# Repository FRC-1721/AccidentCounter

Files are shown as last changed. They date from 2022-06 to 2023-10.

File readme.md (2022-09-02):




Watch the [Youtube Video here.](https://www.youtube.com/watch?v=R463rN57n-0)

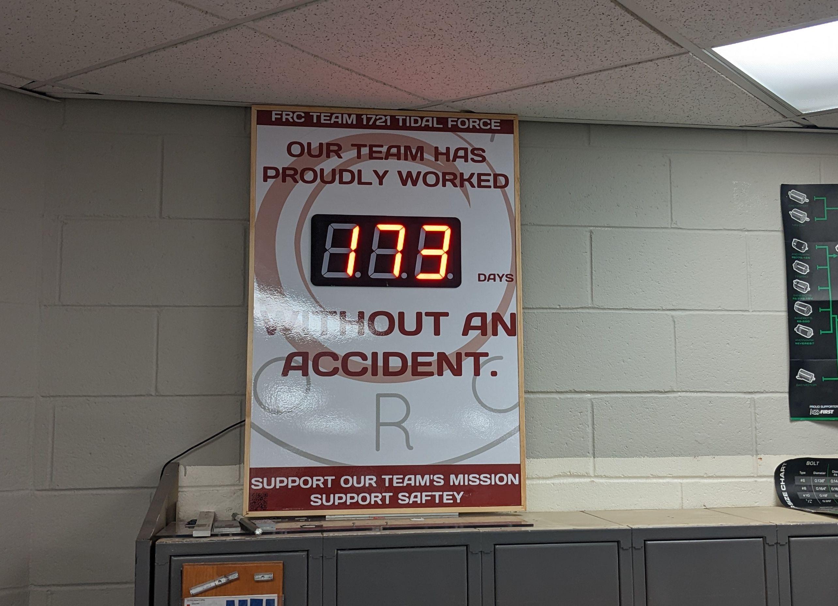
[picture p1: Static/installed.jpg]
The sign installed in the build space


# Welcome!

This repo contains all the firmware and hardware for Tidal Force's "Days
Worked Without Incident" counter.

If you're looking for the latest docs/builds, see our [Releases Page](https://github.com/FRC-1721/AccidentCounter/releases).

# Getting Started

First, clone this repo (and optionally checkout a branch)

```shell
git clone https://github.com/FRC-1721/AccidentCounter.git
cd AccidentCounter
git checkout new_board
```

# Init Submodules

Some libraries and resources are included as submodules, run the following
command to initialize them before opening the main sch

(If you get a missing library error, make sure to do this)

```shell
git submodule update --init --recursive
```

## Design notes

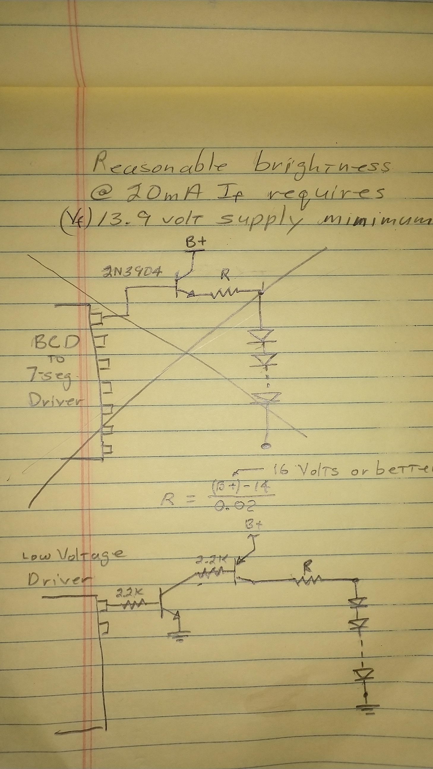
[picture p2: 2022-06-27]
CAD/schematic_with_circuit.jpeg

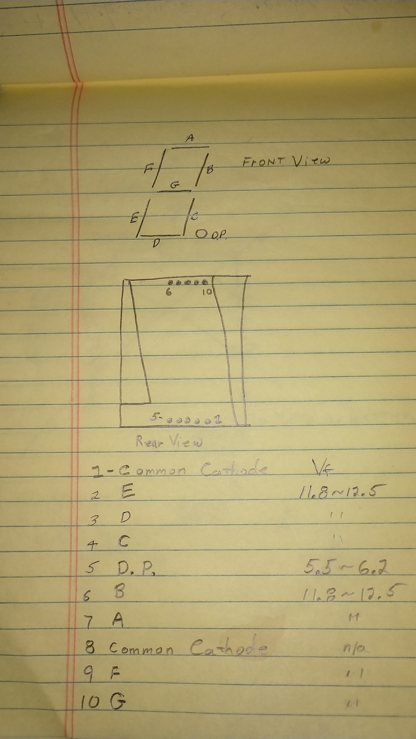
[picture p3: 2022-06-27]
CAD/schematic.png

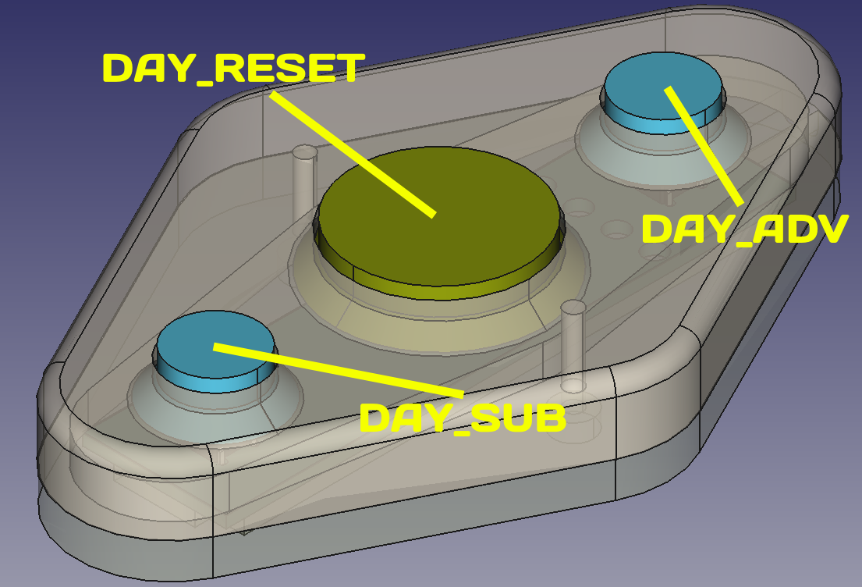
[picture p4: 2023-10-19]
Graphics/ExternalButton.png

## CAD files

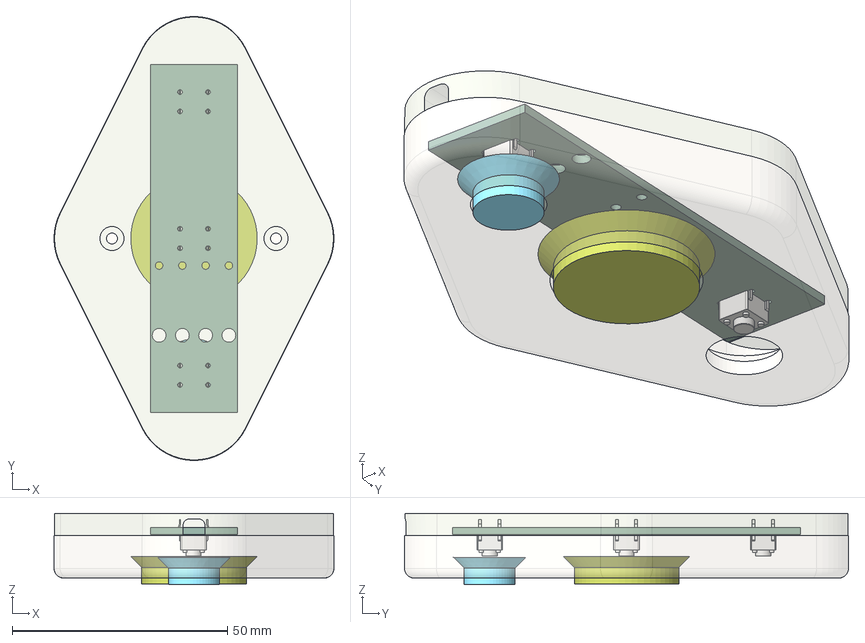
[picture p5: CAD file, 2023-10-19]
CAD/ExternalButton.FCStd
65.0 x 103.1 x 16.5 mm
Top
Small Button
Big Button
Bottom
_autosave-Controller PCB

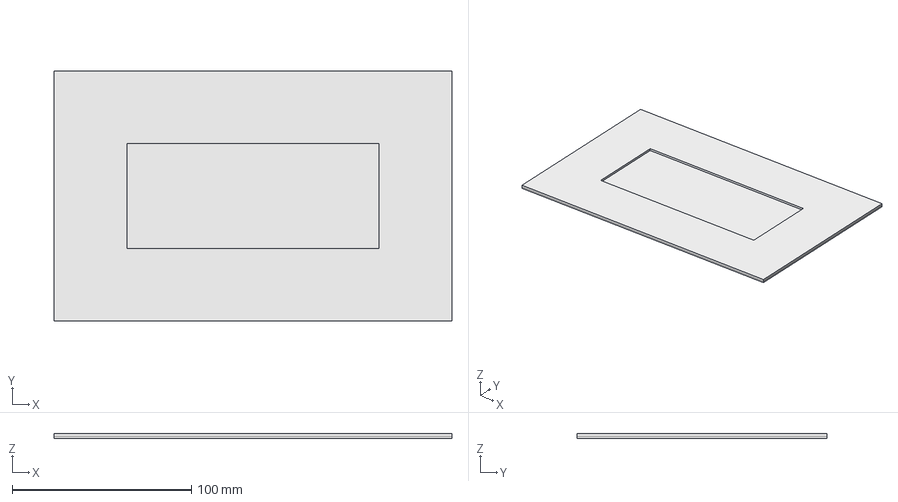
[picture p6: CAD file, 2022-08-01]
Hardware/Segment_Display_Board/Stencils and Templates/SolderMaskStencil.FCStd
222.2 x 139.7 x 2.60 mm

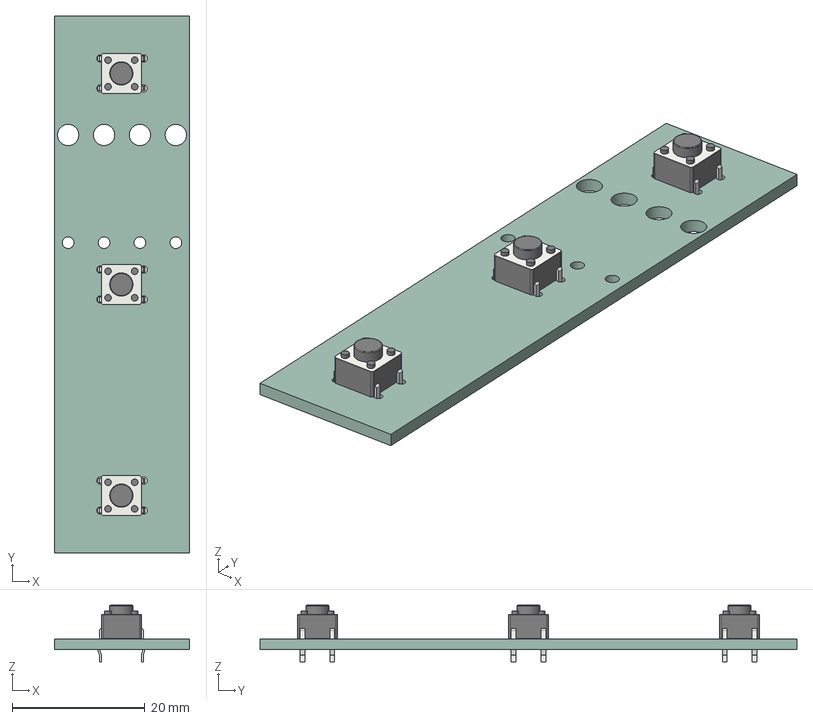
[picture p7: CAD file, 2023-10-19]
CAD/Controller.step
20.3 x 80.8 x 8.50 mm
_autosave-Controller PCB

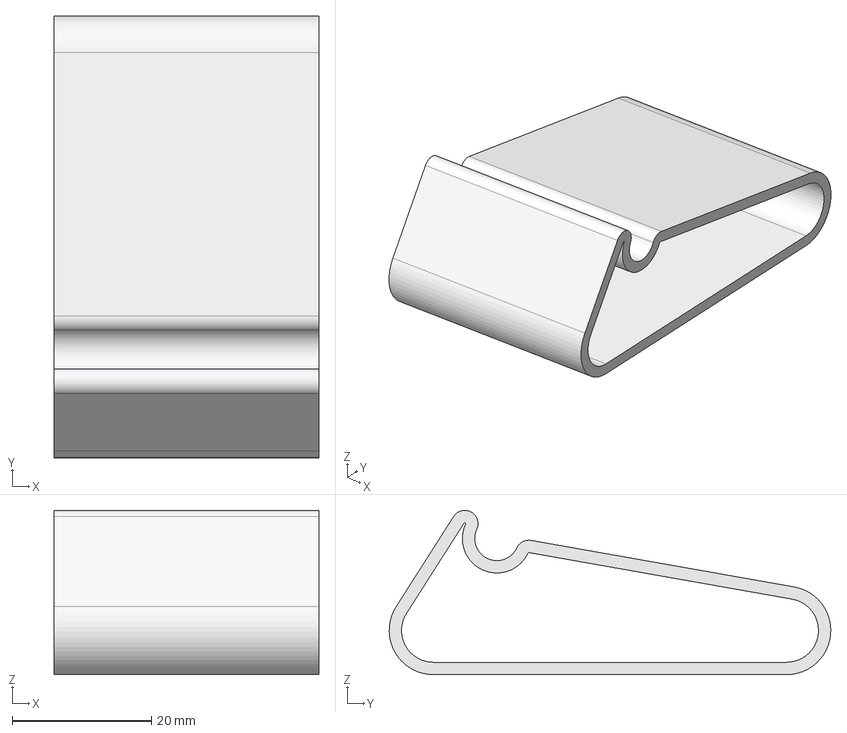
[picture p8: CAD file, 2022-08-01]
CAD/PosterHolder.FCStd
38.1 x 63.5 x 23.6 mm

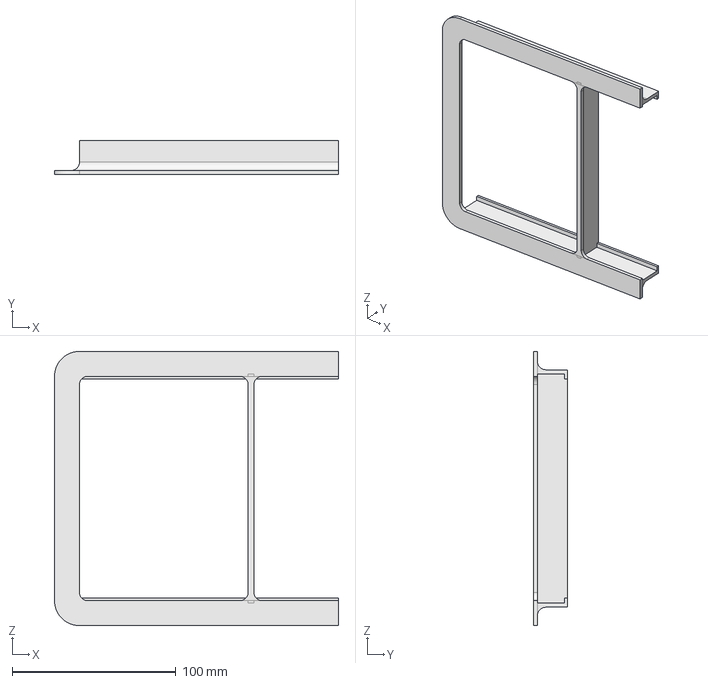
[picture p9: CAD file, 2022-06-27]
CAD/7Segment Bracket.FCStd
173.6 x 21.0 x 167.6 mm

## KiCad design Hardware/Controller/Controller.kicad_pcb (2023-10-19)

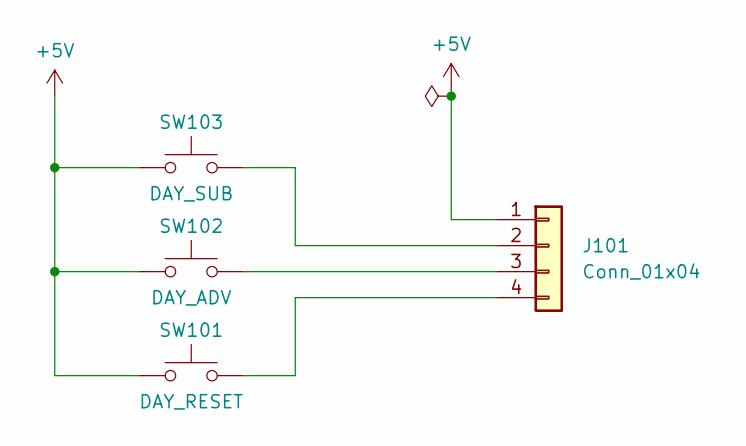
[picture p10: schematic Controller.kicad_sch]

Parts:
J101: Conn_01x04; SolderWire-1sqmm_1x04_P5.4mm_D1.4mm_OD2.7mm_Relief
SW101: DAY_RESET; SW_PUSH_6mm_H5mm
SW102: DAY_ADV; SW_PUSH_6mm_H5mm
SW103: DAY_SUB; SW_PUSH_6mm_H5mm

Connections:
+5V: J101.1, SW101.1, SW102.1, SW103.1
unnamed: J101.2, SW103.2
unnamed: J101.3, SW102.2
unnamed: J101.4, SW101.2

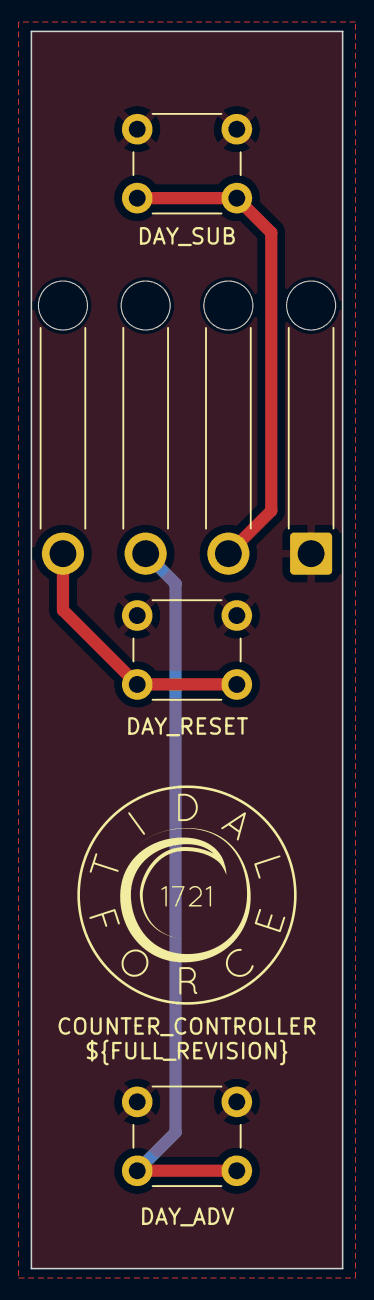
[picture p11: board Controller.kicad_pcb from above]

Board: 2 copper layers, 20.3 x 80.8 mm, 4 parts (0 on the bottom side), 4 nets.

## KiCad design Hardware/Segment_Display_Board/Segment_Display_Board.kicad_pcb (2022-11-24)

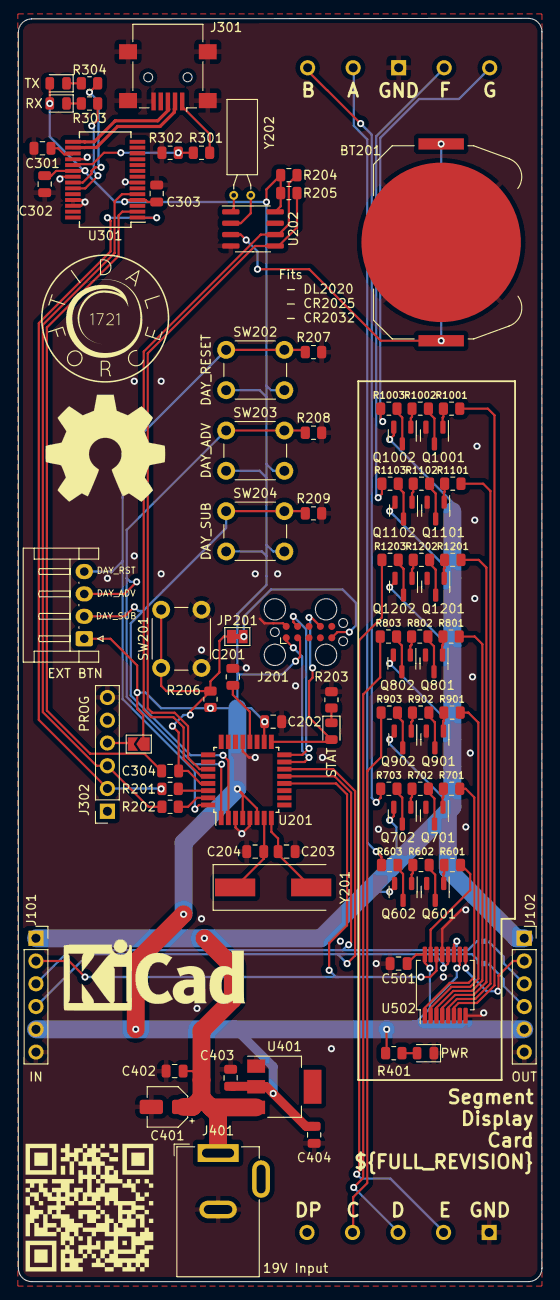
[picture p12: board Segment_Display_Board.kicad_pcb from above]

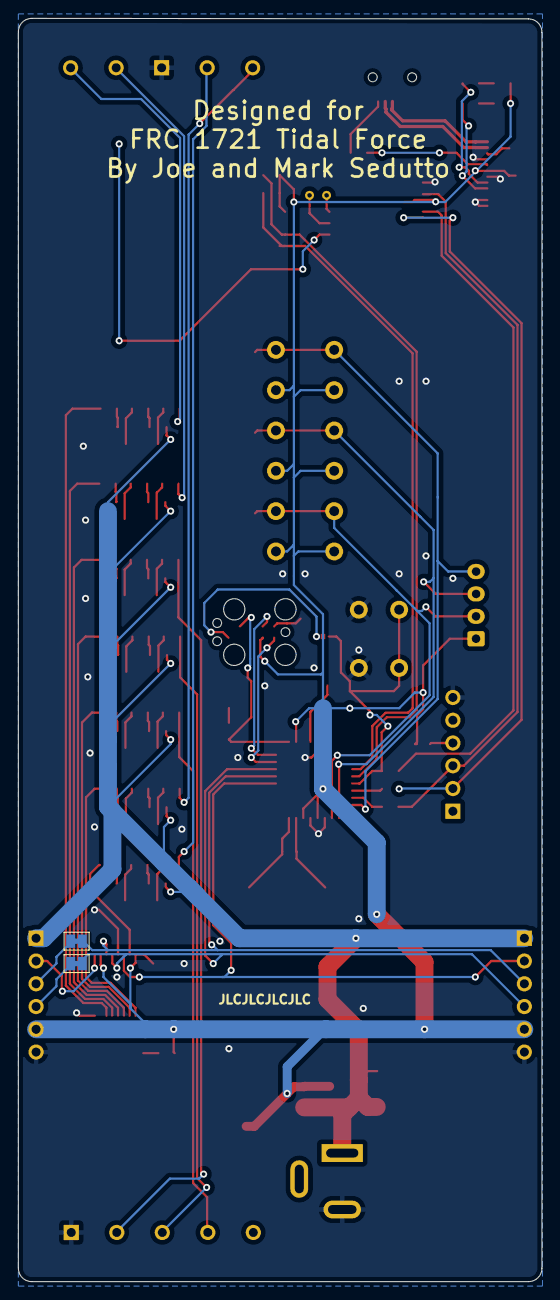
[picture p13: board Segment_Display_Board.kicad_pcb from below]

Board: 2 copper layers, 58.4 x 141.0 mm, 90 parts (2 on the bottom side), 84 nets.

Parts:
BT201: 3v; BatteryHolder_Keystone_3034_1x20mm
C201, C202: 100nf; C_0805_2012Metric
C203, C204: 22pf; C_0805_2012Metric
C301, C302, C303, C304, C402, C403, C501: 100nF; C_0805_2012Metric
C401: 10uf; CP_Elec_4x3
C404: 1uF; C_0805_2012Metric
D201: STAT; LED_0805_2012Metric
D301: RX; LED_0805_2012Metric
D302: TX; LED_0805_2012Metric
D401: PWR; LED_0805_2012Metric
J101: IN; PinSocket_1x06_P2.54mm_Vertical
J102: OUT; PinSocket_1x06_P2.54mm_Vertical
J201: Tag Connect; Tag-Connect_TC2050-IDC-FP_2x05_P1.27mm_Vertical
J202: EXT BTN; JST_EH_S4B-EH_1x04_P2.50mm_Horizontal
J301: USB_B_Micro; USB_Mini-B_Lumberg_2486_01_Horizontal
J302: PROG; PinSocket_1x06_P2.54mm_Vertical
J401: 19V Input; BarrelJack_GCT_DCJ200-10-A_Horizontal
JP201: RSTBridge; SolderJumper-2_P1.3mm_Bridged_Pad1.0x1.5mm
JP301: SolderJumper_2_Open; SolderJumper-2_P1.3mm_Open_TrianglePad1.0x1.5mm
JP501, JP502: SolderJumper_2_Bridged; SolderJumper-2_P1.3mm_Bridged_Pad1.0x1.5mm
Q601, Q701, Q801, Q901, Q1001, Q1101, Q1201: MMBT3904; SOT-23
Q602, Q702, Q802, Q902, Q1002, Q1102, Q1202: MMBT3906; SOT-23
R201, R202, R203, R206, R303, R304, R401: 1K; R_0805_2012Metric
R204, R205, R207, R208, R209, R302, R601, R701, R801, R901, R1001, R1101, R1201: 10K; R_0805_2012Metric
R301: 4K7; R_0805_2012Metric
R602, R702, R802, R902, R1002, R1102, R1202: 2K2; R_0805_2012Metric
R603, R703, R803, R903, R1003, R1103, R1203: 680R; R_0805_2012Metric
SW201: RESET; SW_PUSH_6mm_H5mm
SW202: DAY_RESET; SW_PUSH_6mm_H5mm
SW203: DAY_ADV; SW_PUSH_6mm_H5mm
SW204: DAY_SUB; SW_PUSH_6mm_H5mm
U201: ATmega328P-A; TQFP-32_7x7mm_P0.8mm
U202: DS1307Z+; SOIC-8_3.9x4.9mm_P1.27mm
U301: FT232RL; SSOP-28_5.3x10.2mm_P0.65mm
U401: NCV1117ST50T3G; SOT-223
U501: 5inSegment
U502: SN74HC595
Y201: 16mHz; Crystal_SMD_HC49-SD
Y202: 32.768kHz; Crystal_C38-LF_D3.0mm_L8.0mm_Horizontal

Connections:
+3.3V: C301.1, U301.17 (3V3OUT)
+5V: C202.1, C302.1, C303.1, C403.1, C404.1, C501.1, D301.2 (A), D302.2 (A), J101.5, J102.5, J201.2, J202.1, JP301.1 (A), R204.1, R205.1, R206.1, R401.1, SW202.2, SW203.2, SW204.2, U201.4 (VCC), U201.6 (VCC), U201.18 (AVCC), U202.8 (VCC), U301.4 (VCCIO), U301.20 (VCC), U401.2 (VO), U502.10 (SRCLR), U502.16 (VCC)
+19V: C401.1, C402.1, J101.1, J102.1, J401.1, Q602.2 (E), Q702.2 (E), Q802.2 (E), Q902.2 (E), Q1002.2 (E), Q1102.2 (E), Q1202.2 (E), U401.3 (VI)
/C_OUT: J101.3, JP502.1 (A), U201.13 (PB1), U502.11 (SRCLK)
/D_OUT: J101.2, U201.12 (PB0), U502.14 (SER)
/Display Card/CLOCK_OUT: J102.3, JP502.2 (B)
/Display Card/DATA_OUT: J102.2, U502.9 (QH')
/Display Card/LATCH_OUT: J102.4, JP501.2 (B)
/Display Card/SEG_A: R601.1, U502.15 (QA)
/Display Card/SEG_A_LAMP: R603.2, U501.2 (A)
/Display Card/SEG_B: R701.1, U502.1 (QB)
/Display Card/SEG_B_LAMP: R703.2, U501.1 (B)
/Display Card/SEG_C: R901.1, U502.2 (QC)
/Display Card/SEG_C_LAMP: R903.2, U501.7 (C)
/Display Card/SEG_D: R801.1, U502.3 (QD)
/Display Card/SEG_D_LAMP: R803.2, U501.8 (D)
/Display Card/SEG_E: R1201.1, U502.4 (QE)
/Display Card/SEG_E_LAMP: R1203.2, U501.9 (E)
/Display Card/SEG_F: R1101.1, U502.5 (QF)
/Display Card/SEG_F_LAMP: R1103.2, U501.4 (F)
/Display Card/SEG_G: R1001.1, U502.6 (QG)
/Display Card/SEG_G_LAMP: R1003.2, U501.5 (G)
/L_OUT: J101.4, JP501.1 (A), U201.14 (PB2), U502.12 (RCLK)
/MCU/DAY_ADVANCE: J202.3, R208.1, SW203.1, U201.1 (PD3)
/MCU/DAY_RESET: J202.4, R207.1, SW202.1, U201.32 (PD2)
/MCU/DAY_SUBTRACT: J202.2, R209.1, SW204.1, U201.2 (PD4)
/MCU/ICSP_MISO: J201.9, U201.16 (PB4)
/MCU/ICSP_MOSI: J201.1, U201.15 (PB3)
/MCU/ICSP_RST: J201.5, JP201.2 (B)
/MCU/ICSP_SCK: D201.2 (A), J201.7, U201.17 (PB5)
/MCU/RST: C304.1, JP201.1 (A), R206.2, SW201.1, U201.29 (~RESET/PC6)
/MCU/RXD: J302.2, R201.2, U301.1 (TXD)
/MCU/SCL: R204.2, U201.28 (PC5), U202.6 (SCL)
/MCU/SDA: R205.2, U201.27 (PC4), U202.5 (SDA)
/MCU/TXD: J302.3, R202.2, U301.5 (RXD)
/USB/USB+: J301.3 (D+), U301.15 (USBD+)
/USB/USB-: J301.2 (D-), U301.16 (USBD-)
GND: BT201.2 (-), C201.2, C202.2, C203.2, C204.2, C301.2, C302.2, C303.2, C401.2, C402.2, C403.2, C404.2, C501.2, D401.1 (K), J101.6, J102.6, J201.10, J301.5 (GND), J301.6 (Shield), J302.6, J401.2, Q601.2 (E), Q701.2 (E), Q801.2 (E), Q901.2 (E), Q1001.2 (E), Q1101.2 (E), Q1201.2 (E), R203.1, R207.2, R208.2, R209.2, R302.1, SW201.2, U201.3 (GND), U201.5 (GND), U201.21 (GND), U202.4 (GND), U301.7 (GND), U301.18 (GND), U301.21 (GND), U301.25 (AGND), U301.26 (TEST), U401.1 (GND), U501.3 (GND), U501.10 (GND), U502.8 (GND), U502.13 (OE)
unnamed: BT201.1 (+), U202.3 (VBAT)
unnamed: C201.1, U201.20 (AREF)
unnamed: C203.1, U201.8 (XTAL2/PB7), Y201.2
unnamed: C204.1, U201.7 (XTAL1/PB6), Y201.1
unnamed: C304.2, U301.2 (DTR)
unnamed: D201.1 (K), R203.2
unnamed: D301.1 (K), R303.2
unnamed: D302.1 (K), R304.1
unnamed: D401.2 (A), R401.2
unnamed: J302.4, JP301.2 (B)
unnamed: Q601.1 (B), R601.2
unnamed: Q601.3 (C), R602.1
unnamed: Q602.1 (B), R602.2
unnamed: Q602.3 (C), R603.1
unnamed: Q701.1 (B), R701.2
unnamed: Q701.3 (C), R702.1
unnamed: Q702.1 (B), R702.2
unnamed: Q702.3 (C), R703.1
unnamed: Q801.1 (B), R801.2
unnamed: Q801.3 (C), R802.1
unnamed: Q802.1 (B), R802.2
unnamed: Q802.3 (C), R803.1
unnamed: Q901.1 (B), R901.2
unnamed: Q901.3 (C), R902.1
unnamed: Q902.1 (B), R902.2
unnamed: Q902.3 (C), R903.1
unnamed: Q1001.1 (B), R1001.2
unnamed: Q1001.3 (C), R1002.1
unnamed: Q1002.1 (B), R1002.2
unnamed: Q1002.3 (C), R1003.1
unnamed: Q1101.1 (B), R1101.2
unnamed: Q1101.3 (C), R1102.1
unnamed: Q1102.1 (B), R1102.2
unnamed: Q1102.3 (C), R1103.1
unnamed: Q1201.1 (B), R1201.2
unnamed: Q1201.3 (C), R1202.1
unnamed: Q1202.1 (B), R1202.2
unnamed: Q1202.3 (C), R1203.1
unnamed: R201.1, U201.30 (PD0)
unnamed: R202.1, U201.31 (PD1)
unnamed: R301.1, R302.2, U301.19 (~RESET)
unnamed: R303.1, U301.23 (CBUS0)
unnamed: R304.2, U301.22 (CBUS1)
unnamed: U202.1 (X1), Y202.2
unnamed: U202.2 (X2), Y202.1
VBUS: J301.1 (VBUS), R301.2

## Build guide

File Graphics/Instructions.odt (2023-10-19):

Basic Operation Guide

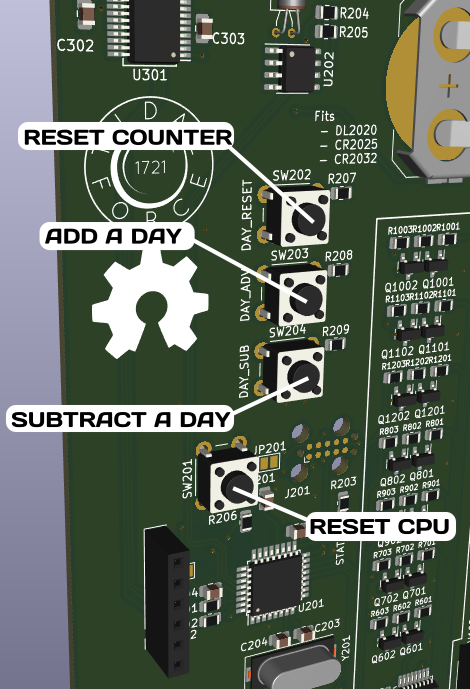
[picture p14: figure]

# Basics

There are 4 buttons on the back of the display module.

Note that only the first circuit board has buttons.

## DAY_RESET

Resets the counter, press this if an accident occurs (but not first! Treat the poor person first!)

When you press this, the sign will count down to 0, and then reset the time, and will count up from the time you push this button. (This is probably the button you’re looking for)

## DAY_ADV

This button will add a day to the counter, you can press it several times to tick the counter to a specific number.

The counter will continue counting from the date you set

## DAY_SUB

Opposite of DAY_ADV, subtracts one day and starts counting from that date.

## Reset

Pressing this resets the CPU, it doesn't reset the day, just restarts the board. If the battery is powered, then this will briefly turn the display off and resume showing the same day, if the battery is dead then this may accidentally reset the clock. (You probably don’t need to press this)

Remote Operation Guide

Included in v1.3.1 is an external remote! The remote has all the same buttons as above.


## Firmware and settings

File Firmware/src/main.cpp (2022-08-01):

/**
 * @file main.cpp
 * @author Joe
 * @brief Source code for Tidal Force's "Days Worked Without Incident" counter.
 */

// Libs
#include <Arduino.h>
#include <avr/wdt.h>
#include <Wire.h>
#include <RTClib.h>
#include <Bounce2.h>

// Headers
#include "boardPins.h"

// Libs
#include "display.h"

// Objects
Display display(3, LATCH_PIN, CLOCK_PIN, DATA_PIN);
RTC_DS1307 rtc;

// Buttons
const uint8_t buttonInterval = 8;
Bounce2::Button advButton = Bounce2::Button();
Bounce2::Button subButton = Bounce2::Button();
Bounce2::Button rstButton = Bounce2::Button();

void setup()
{
    // Setup serial
    delay(200);
    Serial.begin(115200);
    Serial.println(MOTD);

    // Configure Watchdog
    wdt_enable(WDTO_4S);

    // Pins
    pinMode(STAT_LED, OUTPUT);
    pinMode(LATCH_PIN, OUTPUT);
    pinMode(CLOCK_PIN, OUTPUT);
    pinMode(DATA_PIN, OUTPUT);

    // Setup RTC
    if (!rtc.begin())
    {
        Serial.println("\x1B[31mCouldn't find RTC!\x1B[0m");
        Serial.flush();
        while (1)
        {
            display.setErr(); // Set error on display
            delay(100);
        }
    }

    if (!rtc.isrunning()) // If the rtc is NOT running
    {
        rtc.adjust(DateTime(SECONDS_PER_DAY * 0)); // Set the time back to 0
    }

    // Attach buttons
    advButton.attach(ADV_PIN, INPUT);
    subButton.attach(SUB_PIN, INPUT);
    rstButton.attach(RST_PIN, INPUT);

    // Configure buttons
    advButton.interval(buttonInterval);
    advButton.setPressedState(LOW);
    subButton.interval(buttonInterval);
    subButton.setPressedState(LOW);
    rstButton.interval(buttonInterval);
    rstButton.setPressedState(LOW);
}

void loop()
{
    // Reset the watchdog counter
    wdt_reset();

    // Update buttons
    advButton.update();
    subButton.update();
    rstButton.update();

    // Get time
    DateTime now = rtc.now();
    uint16_t currentDay = now.unixtime() / SECONDS_PER_DAY;

    // Flash LED
    digitalWrite(STAT_LED, now.unixtime() % 2 == 0);

    // Set time
    display.setNum(currentDay);

    // Loop pause
    delay(10);

    if (advButton.pressed())
    {
        rtc.adjust(DateTime(SECONDS_PER_DAY * (currentDay + 1))); // One extra day
    }

    if (subButton.pressed())
    {
        if (currentDay > 0)
        {
            rtc.adjust(DateTime(SECONDS_PER_DAY * (currentDay - 1))); // One less day}
        }
        else
        {
            // You cant go less than 0
            display.setErr();
            delay(800);
        }
    }

    if (rstButton.pressed())
    {
        // Cool animation
        for (uint16_t i = 0; i < currentDay; i++)
        {
            display.setNum(currentDay - i);
            wdt_reset();
            delay((2000 / (currentDay - i)) + 100); // Speeds up as we approach
        }

        rtc.adjust(DateTime(SECONDS_PER_DAY * 0)); // One extra day
    }
}

void serialEvent()
{
    while (Serial.available())
    {
        int16_t newDay = Serial.parseInt();
        if (newDay != 0)
        {
            rtc.adjust(DateTime(SECONDS_PER_DAY * newDay));
        }
    }
}

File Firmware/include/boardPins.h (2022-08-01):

#ifndef _BOARD_PINS_H
#define _BOARD_PINS_H

// LEDs
#define STAT_LED 13

// shift definitions
#define LATCH_PIN 10
#define CLOCK_PIN 9
#define DATA_PIN 8

// Buttons
#define RST_PIN 2
#define ADV_PIN 3
#define SUB_PIN 4

// Board
#define NUM_SEGMENTS 3

#endif

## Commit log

2022-06-24 Create base drawings + sch for new brd
    [Power.kicad_sch, days_worked_counter.kicad_pcb, days_worked_counter.kicad_sch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]
2022-06-24 Add tidal force
    [days_worked_counter.kicad_pcb, days_worked_counter.kicad_sch, usb.kicad_sch]
2022-06-24 Cleanup more stuff
    [days_worked_counter.kicad_pcb, days_worked_counter.kicad_sch, display_card.kicad_sch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]
2022-06-24 Add all the cool stuff
    [Power.kicad_sch, days_worked_counter.kicad_pcb, days_worked_counter.kicad_sch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]
2022-06-27 Even more stuff
    [Power.kicad_sch, days_worked_counter.kicad_pcb, days_worked_counter.kicad_sch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]
2022-06-27 Add drawings and pin placements
    [days_worked_counter.kicad_sch, display_card.kicad_sch]
2022-06-27 Include 7 Segment Bracket
    [7Segment Bracket.FCStd]
2022-06-27 Add stuff
    [7Segment Bracket.FCStd, Power.kicad_sch, days_worked_counter.kicad_sch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]
2022-06-28 get input from @ka2qfx
    [Power.kicad_sch, days_worked_counter.kicad_pcb, days_worked_counter.kicad_sch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]
2022-06-28 Thank @ka2qfx for fixups!
    [days_worked_counter.kicad_pcb, days_worked_counter.kicad_sch, display_card.kicad_sch]
2022-06-28 Change direction
    [buffer.kicad_sch, days_worked_counter.kicad_pcb, days_worked_counter.kicad_sch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]
2022-06-28 With thanks to @ka2qfx
    [Power.kicad_sch, buffer.kicad_sch, days_worked_counter.kicad_pcb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]
2022-06-28 move all
    [Power.kicad_sch, buffer.kicad_sch, display_card.kicad_sch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]
2022-06-28 move all again
    [Power.kicad_sch, Segment_Display_Board.kicad_pcb, Segment_Display_Board.kicad_sch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]
2022-06-28 Steps for a RC1
    [Segment_Display_Board.kicad_pcb]
2022-06-28 Fix stuff i guess goodnight"
    [Power.kicad_sch, Segment_Display_Board.kicad_pcb, Segment_Display_Board.kicad_sch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]
2022-06-28 Add a bunch more great stuff
    [Segment_Display_Board.kicad_pcb]
2022-06-28 Place hardware orders
    [Power.kicad_sch, Segment_Display_Board.kicad_pcb, Segment_Display_Board.kicad_sch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]
2022-06-28 Add a nice outline so you know what a client brd needs
    [Segment_Display_Board.kicad_pcb]
2022-06-28 Use a different regulator
    [Power.kicad_sch, Segment_Display_Board.kicad_pcb, Segment_Display_Board.kicad_sch]
2022-06-28 include fixups fro EE
    [Power.kicad_sch, Segment_Display_Board.kicad_pcb, Segment_Display_Board.kicad_sch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]
2022-07-18 Add stencil and small text fixup
    [Segment_Display_Board.kicad_pcb, SolderMaskStencil.FCStd]
2022-07-18 Silkscreen cleanup
    [Segment_Display_Board.kicad_pcb]
2022-07-20 Fixup some stuff
    [Segment_Display_Board.kicad_pcb, Segment_Display_Board.kicad_sch, buffer.kicad_sch]
2022-07-20 Works enough to do something basic
    [Segment_Display_Board.kicad_pcb, Segment_Display_Board.kicad_sch, buffer.kicad_sch]
2022-07-21 Include battery info
    [Segment_Display_Board.kicad_pcb]
2022-07-21 Clock still does not work lol~
    [main.cpp]
2022-07-21 Fix a bug where if there was noise on the serial wires it would cause a soft reset
    [main.cpp]
2022-07-21 Fix another bug where you could underflow by spamming day_sub
    [main.cpp]
2022-07-21 Include fancy ICSP programmer (lol)
    [Segment_Display_Board.kicad_pcb, Segment_Display_Board.kicad_sch, mcu.kicad_sch]
2022-07-22 Fix a inturrupt based bug:
    [main.cpp]
2022-07-25 Put together a slightly better firmware and remove some extra bloat, did not find source of the 12 bug..
    [main.cpp]
2022-07-26 Add a poster holder
    [PosterHolder.FCStd]
2022-07-28 Use new 5in symbol and footprint
    [Segment_Display_Board.kicad_pcb, Segment_Display_Board.kicad_sch, display_card.kicad_sch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]
2022-07-31 Change package for 1uF capacitor
    [Power.kicad_sch, Segment_Display_Board.kicad_pcb, Segment_Display_Board.kicad_sch]
2022-08-12 Add breakout for external buttons
    [Segment_Display_Board.kicad_pcb, Segment_Display_Board.kicad_sch, mcu.kicad_sch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]
2022-08-12 Fix DRC
    [Segment_Display_Board.kicad_pcb]
2022-08-16 Move jumper desig
    [Segment_Display_Board.kicad_pcb]
2022-11-22 Minor cleanups
    [Segment_Display_Board.kicad_pcb]
2022-11-23 Possible rewire
    [Segment_Display_Board.kicad_pcb, mcu.kicad_sch]
2022-12-14 Fixup! Fixes an upstream bug where reference values attached to parts were not included on silkscreen.
2023-10-19 Remote Board (#8)
    All checks pass, lets merge this
    [Controller.kicad_pcb, Controller.kicad_sch, Controller.step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]
